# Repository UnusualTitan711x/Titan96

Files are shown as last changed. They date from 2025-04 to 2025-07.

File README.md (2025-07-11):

# Titan96  

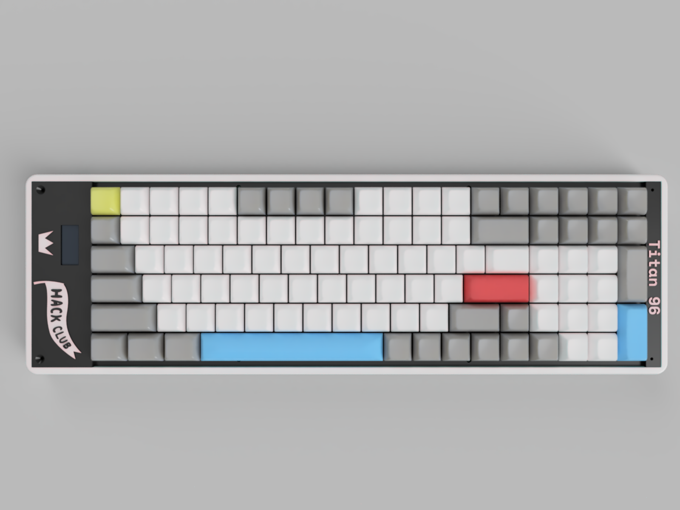
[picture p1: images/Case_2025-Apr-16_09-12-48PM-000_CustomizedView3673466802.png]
Titan96 render


**Titan96** is a compact 96% low-profile mechanical keyboard designed with sleek aesthetic. Powered by **KMK firmware** and built around the **Orpheus Pico microcontroller** by Hack Club.  

## Features  
- **96% Layout** – Compact yet functional, with all essential keys in a dense layout.  
- **Low-Profile Design** – Slimmer keys and case for a modern, ergonomic feel.  
- **KMK Firmware** – Highly customizable keymaps and macros using CircuitPython.  
- **Orpheus Pico MCU** – A powerful and open-source microcontroller by Hack Club.  
- **100 Keys** – Full numpad and navigation keys.  

## Parts
### CAD
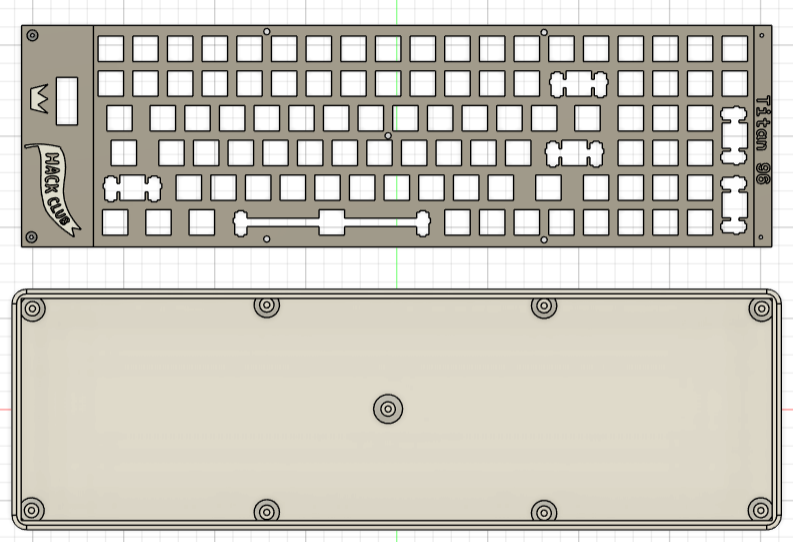
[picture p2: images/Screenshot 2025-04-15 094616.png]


### Schematic
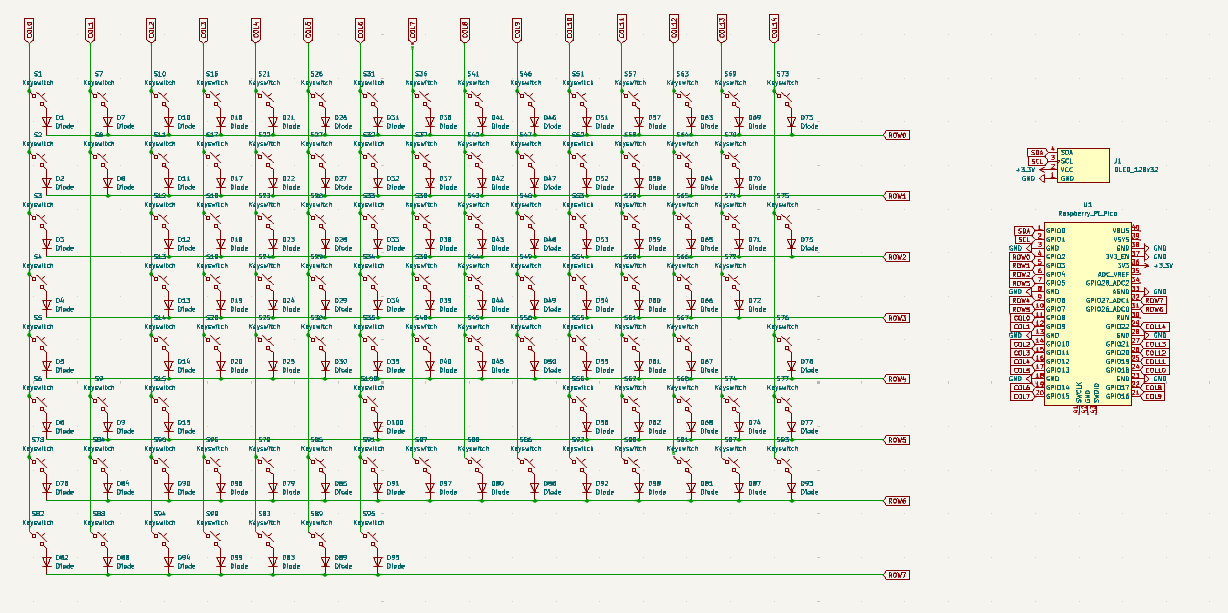
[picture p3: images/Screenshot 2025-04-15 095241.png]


### PCB
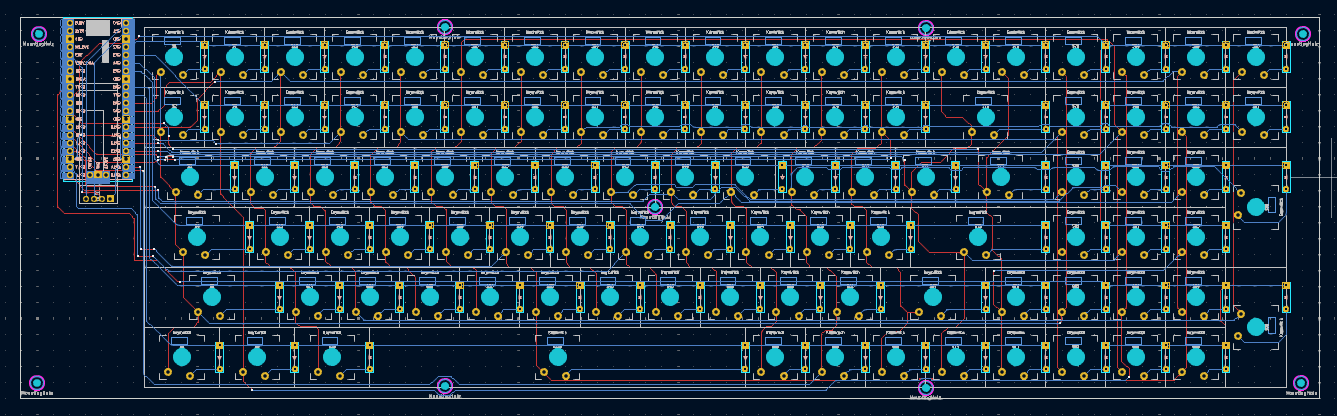
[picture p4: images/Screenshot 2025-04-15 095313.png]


## Firmware & Software  
The Titan96 runs on **KMK**, a Python-based keyboard firmware for CircuitPython-compatible microcontrollers.  

### Setup Instructions  
1. **Flash CircuitPython** onto the Orpheus Pico.  
2. **Install KMK firmware** by copying the KMK files to the microcontroller.  
3. **Configure keymap** by editing `code.py` to match your layout.  
4. **Customize macros, layers, and RGB** (if supported) via KMK.  

For detailed KMK setup, refer to the [official KMK documentation](https://github.com/KMKfw/kmk_firmware).  

## Bill of Materials (BOM)  
| Part | Quantity | Price | Link | Notes |  
|---|---|---|---|---|
| Orpheus Pico MCU | 1 | N/A | N/A | Microcontroller by Hack Club |  
| Low-profile mechanical switches | 100 | $40.07 | [AliExpress](https://www.aliexpress.com/item/1005004620638633.html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) | Gateron Low-Profile |  
| Keycaps | 100 | $22.14 | [AliExpress](https://www.aliexpress.com/item/1005007074678857.html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) | MX stems |  
| PCB | 1 | N/A |  N/A | Custom Titan96 PCB |  
| Plate | 1 |  N/A | N/A |3D printed |  
| Case | 1 | N/A | N/A | 3D printed |  
| Diodes | 100 | $4.7 | [AliExpress](https://www.aliexpress.com/item/1005004333197874.html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) | 1N4148 |  
| Stabilizers | 2u x 5, 6.5u x 1 | $15.58 | [AliExpress](https://www.aliexpress.com/item/1005005296240590.html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) | For larger keys (spacebar, Enter, etc.) |  
| OLED Screen 128 x 32 | 1 | $5.36 | [AliExpress](https://www.aliexpress.com/item/1005008670382155.html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) | Screen |  
| M2 screws | 5 | $4.8 | [AliExpress](https://www.aliexpress.com/item/1005004533251852.html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) | To screw the plate into the case |
| M2 threaded inserts | 5 | $5.87 | [AliExpress](https://www.aliexpress.com/item/1005003582355741.html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) | To screw the plate into the case |
 
*NB: All these prices include shipping to Cameroon*

Total : $98.52
## License  
This project is open-source under the **MIT License**.  

## Extra Renders
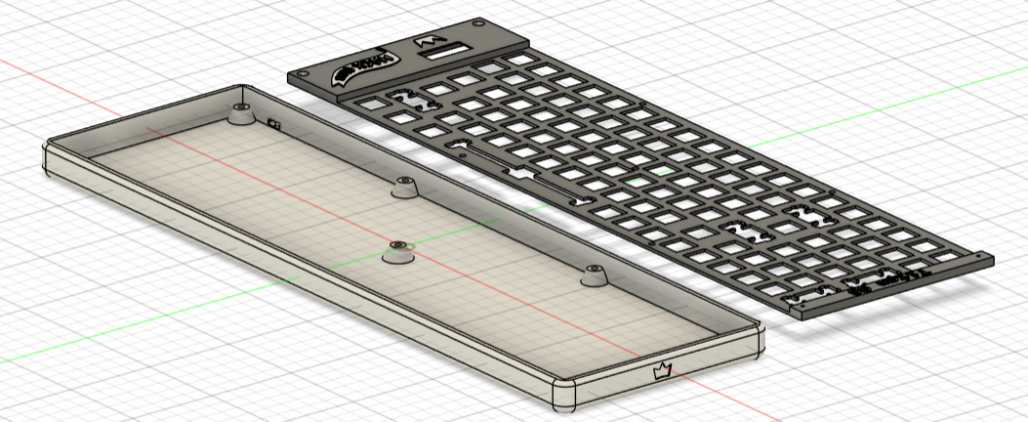
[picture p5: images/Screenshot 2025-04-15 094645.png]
3D Model above

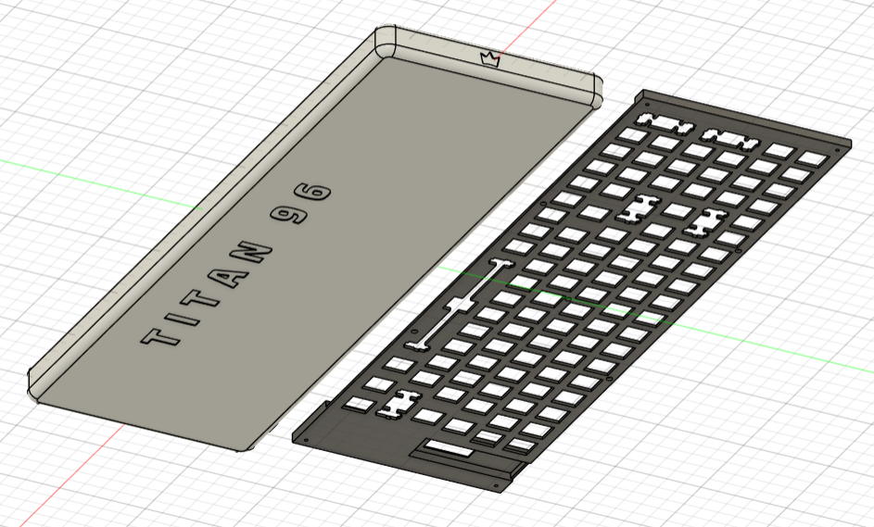
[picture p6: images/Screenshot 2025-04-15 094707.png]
3D Model below

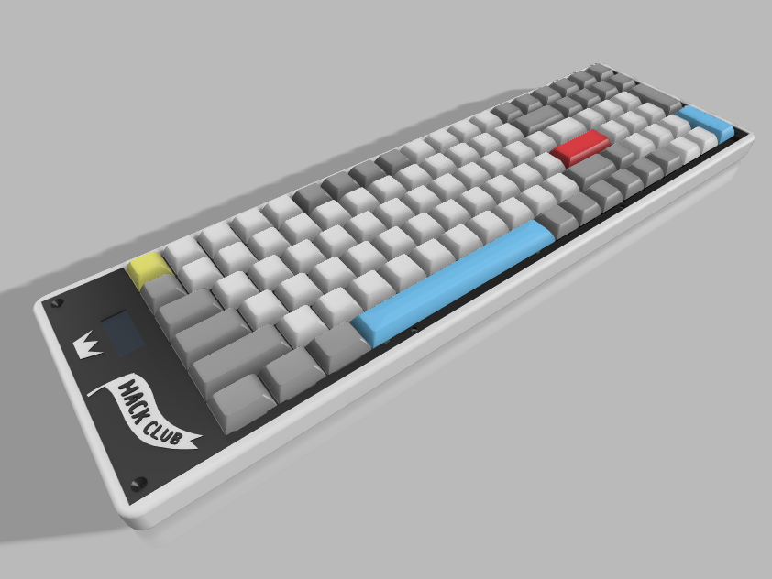
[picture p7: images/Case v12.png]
Full render

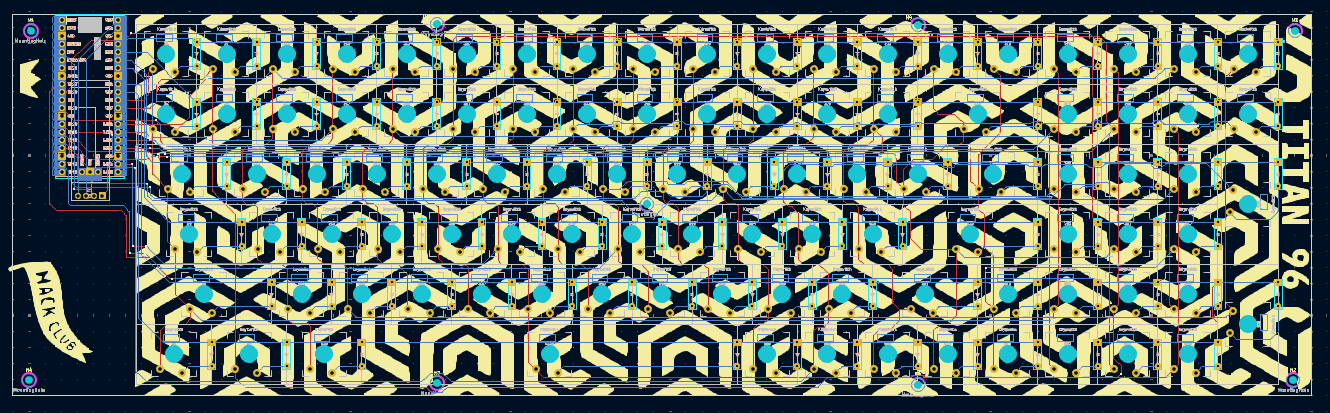
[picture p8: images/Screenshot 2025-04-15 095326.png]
PCB with Silkscreen Art


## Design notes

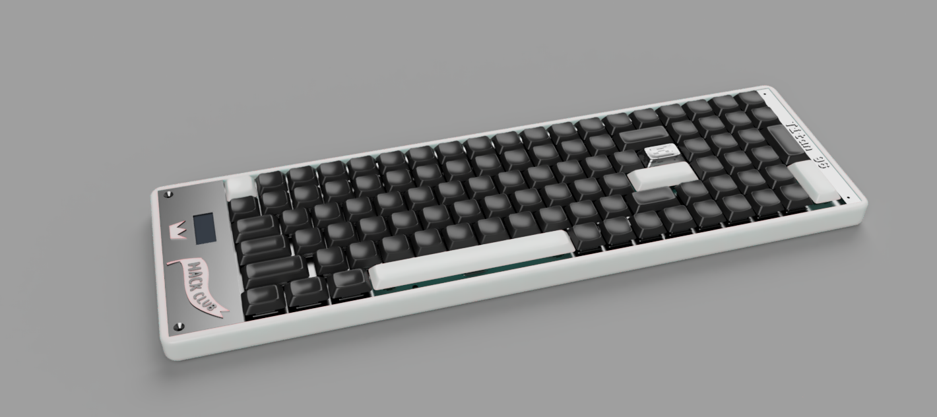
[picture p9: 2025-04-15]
images/26091cd3-cad4-45ae-b3a8-d274d9b3df26.PNG

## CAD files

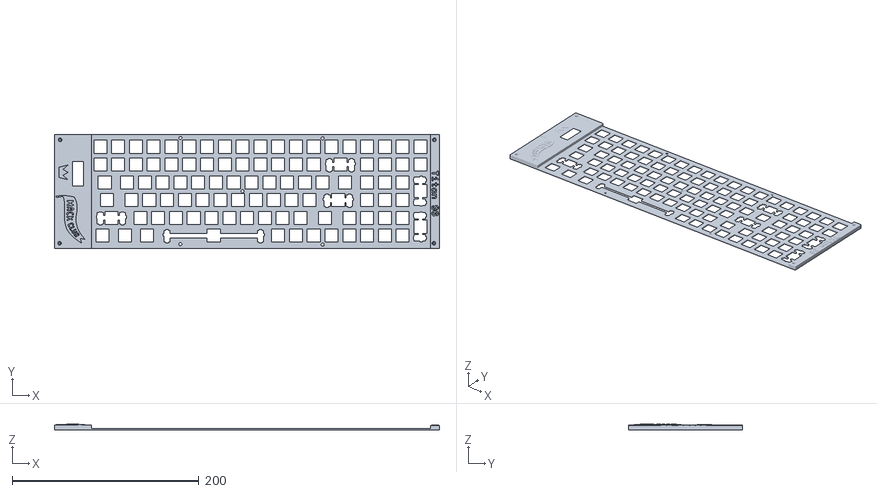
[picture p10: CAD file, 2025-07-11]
production/Plate.stl
412.4 x 121.6 x 6.50

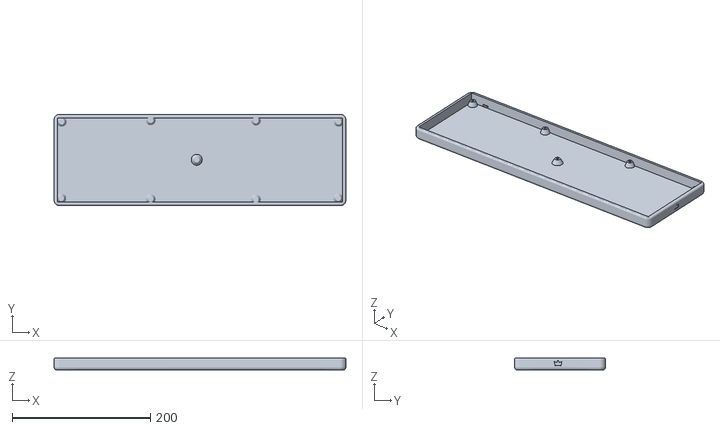
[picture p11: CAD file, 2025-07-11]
production/Case.stl
422.8 x 132.0 x 18.0

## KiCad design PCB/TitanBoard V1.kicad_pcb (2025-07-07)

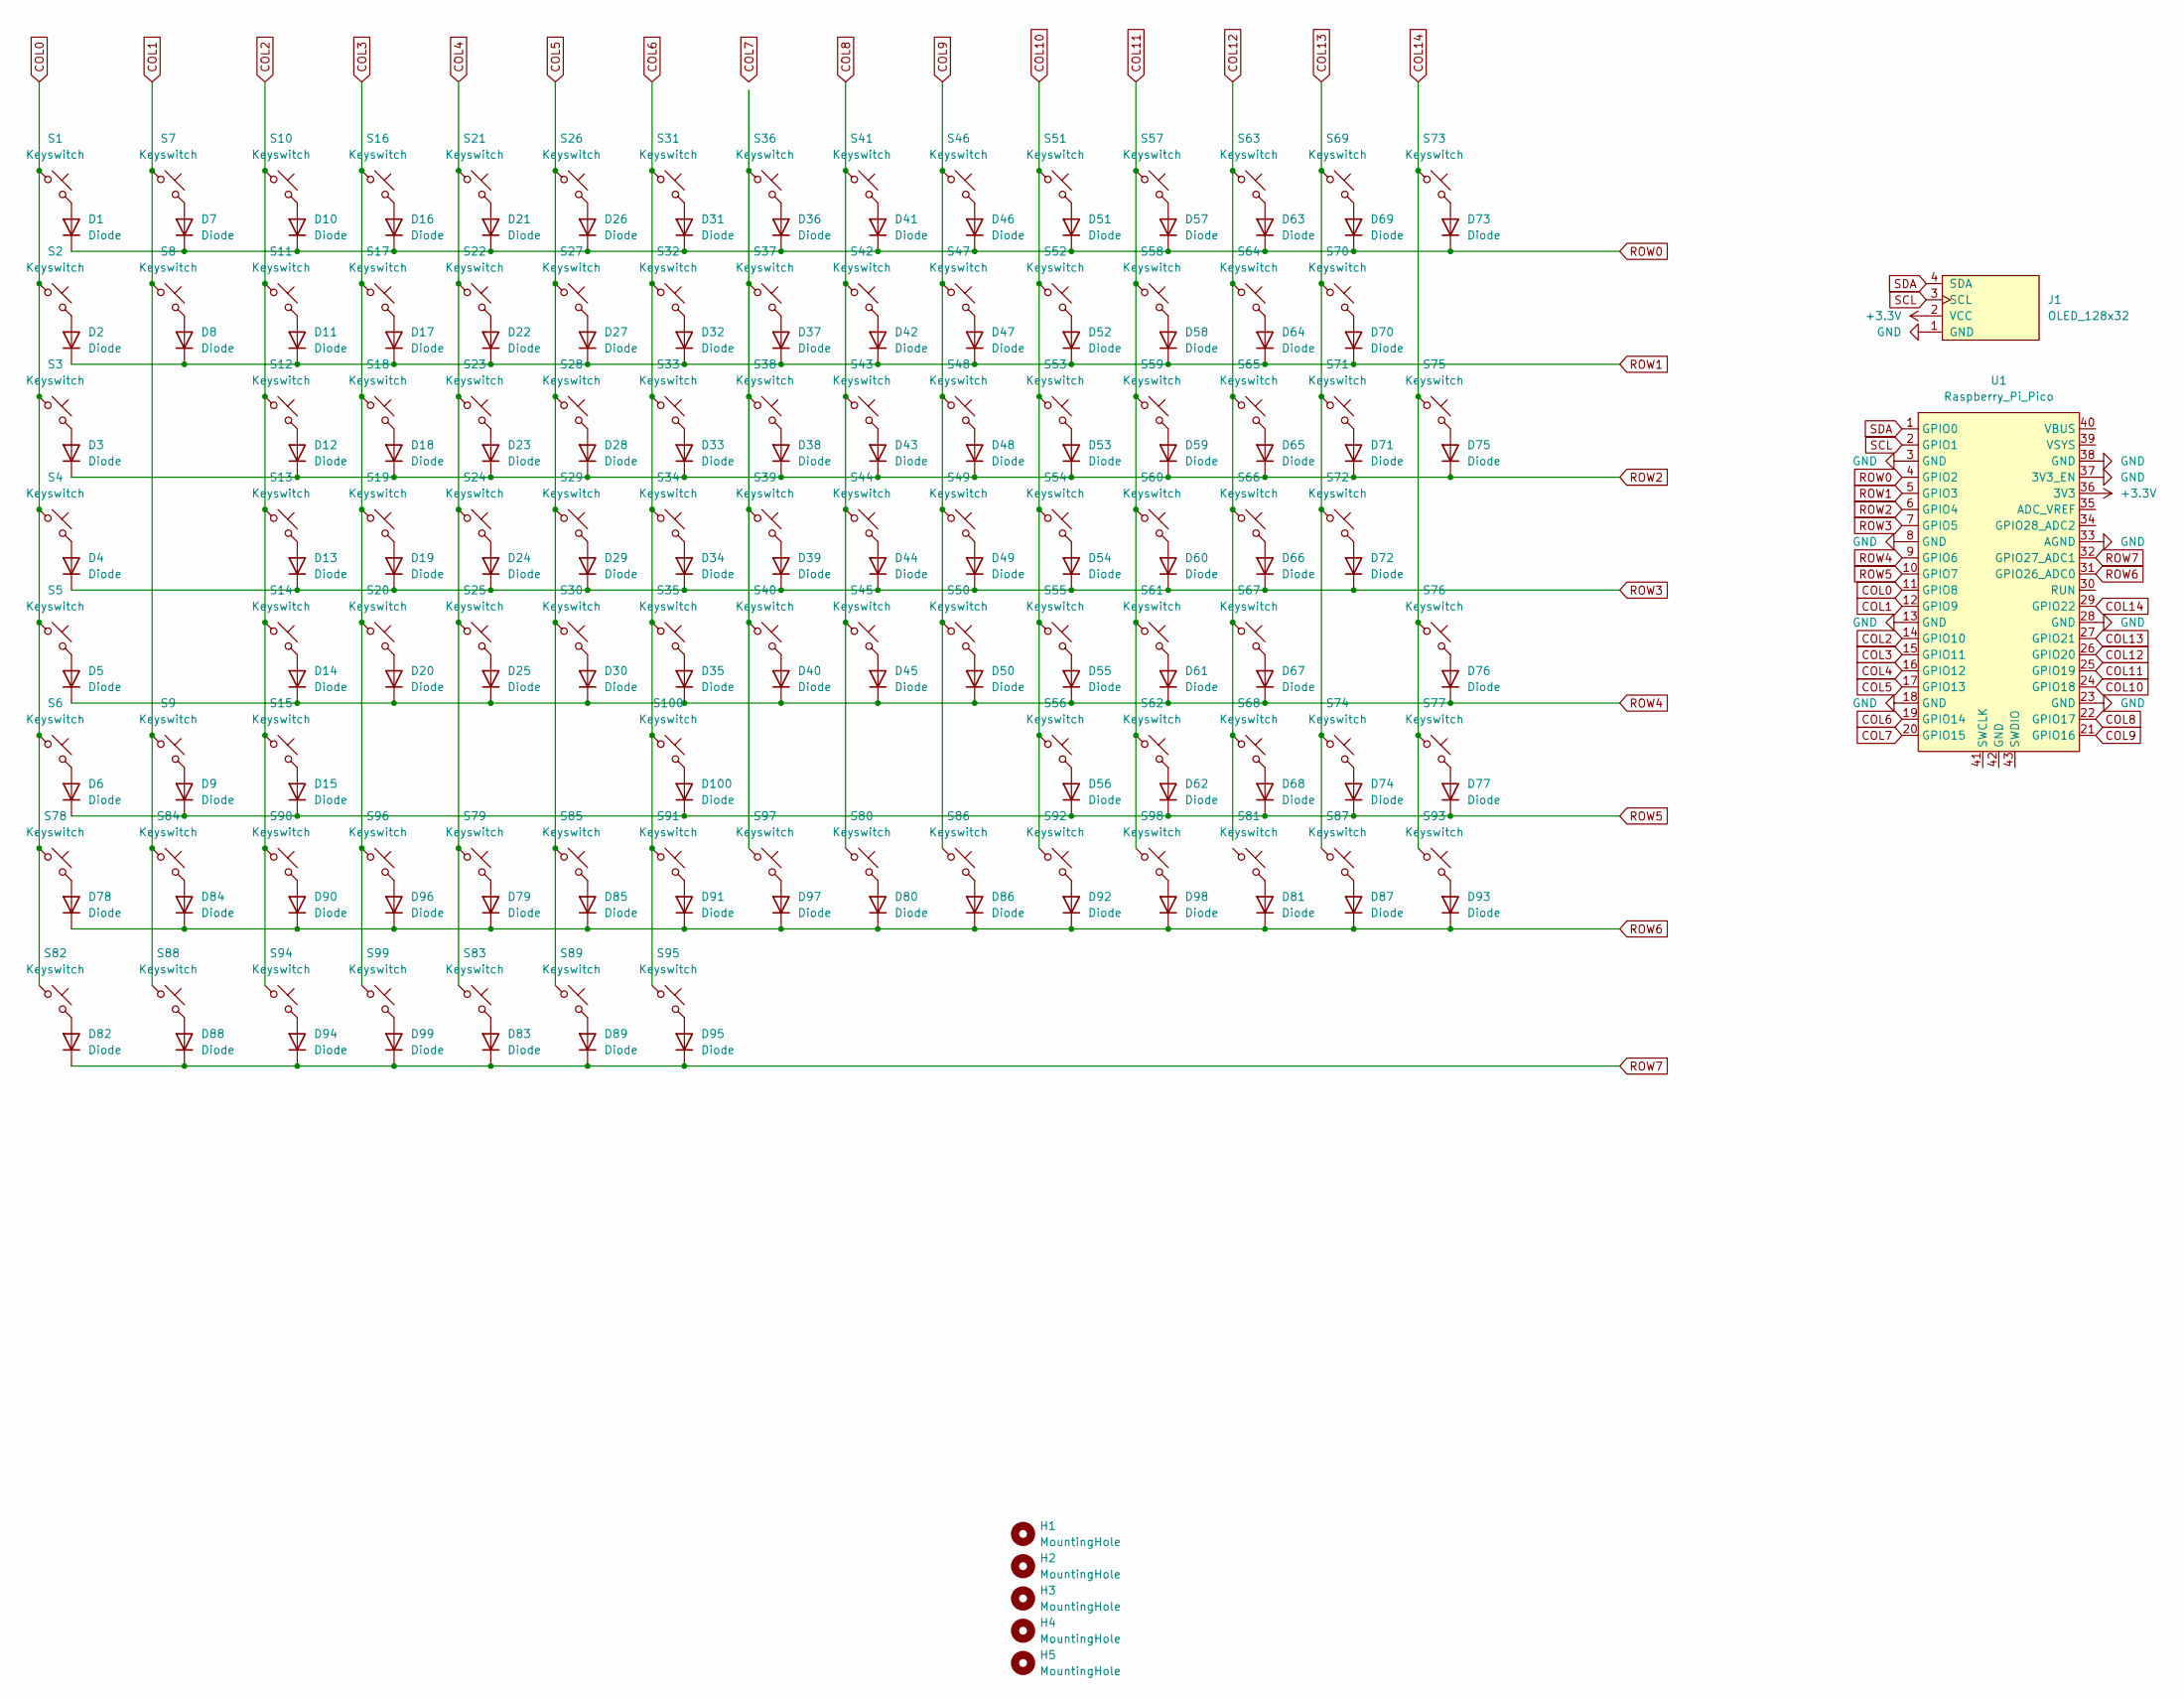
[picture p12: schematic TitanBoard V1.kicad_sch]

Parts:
D1, D2, D3, D4, D5, D6, D7, D8, D9, D10, D11, D12, D13, D14, D15, D16, D17, D18, D19, D20, D21, D22, D23, D24, D25, D26, D27, D28, D29, D30, D31, D32, D33, D34, D35, D36, D37, D38, D39, D40, D41, D42, D43, D44, D45, D46, D47, D48, D49, D50, D51, D52, D53, D54, D55, D56, D57, D58, D59, D60, D61, D62, D63, D64, D65, D66, D67, D68, D69, D70, D71, D72, D73, D74, D75, D76, D77, D78, D79, D80, D81, D82, D83, D84, D85, D86, D87, D88, D89, D90, D91, D92, D93, D94, D95, D96, D97, D98, D99, D100: Diode; Diode_DO-35
H1, H2, H3, H4, H5: MountingHole; MountingHole_2.2mm_M2
J1: OLED_128x32
S1, S2, S7, S8, S10, S11, S12, S13, S14, S16, S17, S18, S19, S20, S21, S22, S23, S24, S25, S26, S27, S28, S29, S30, S31, S32, S33, S34, S35, S36, S37, S38, S39, S40, S41, S42, S43, S44, S45, S46, S47, S48, S49, S50, S51, S52, S53, S54, S55, S56, S57, S58, S59, S60, S61, S62, S63, S64, S65, S66, S68, S69, S71, S73, S74, S76, S77, S78, S79, S80, S81, S82, S83, S84, S85, S86, S87, S88, S89, S90, S91, S92, S93, S94, S95, S96, S97: Keyswitch; Gateron-KS33-Solderable-1U
S3, S75: Keyswitch; Gateron-KS33-Solderable-1.5U
S4, S67: Keyswitch; Gateron-KS33-Solderable-1.75U
S5, S72: Keyswitch; Gateron-KS33-Solderable-2.25U
S6, S9, S15: Keyswitch; Gateron-KS33-Solderable-1.25U
S70, S98, S99: Keyswitch; Gateron-KS33-Solderable-2U
S100: Keyswitch; Gateron-KS33-Solderable-6.25U
U1: Raspberry_Pi_Pico

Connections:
+3.3V: J1.2 (VCC), U1.36 (3V3)
COL0: S1.1, S2.1, S3.1, S4.1, S5.1, S6.1, S78.1, S82.1, U1.11 (GPIO8)
COL1: S7.1, S8.1, S9.1, S84.1, S88.1, U1.12 (GPIO9)
COL2: S10.1, S11.1, S12.1, S13.1, S14.1, S15.1, S90.1, S94.1, U1.14 (GPIO10)
COL3: S16.1, S17.1, S18.1, S19.1, S20.1, S96.1, S99.1, U1.15 (GPIO11)
COL4: S21.1, S22.1, S23.1, S24.1, S25.1, S79.1, S83.1, U1.16 (GPIO12)
COL5: S26.1, S27.1, S28.1, S29.1, S30.1, S85.1, S89.1, U1.17 (GPIO13)
COL6: S31.1, S32.1, S33.1, S34.1, S35.1, S91.1, S95.1, S100.1, U1.19 (GPIO14)
COL7: U1.20 (GPIO15)
COL8: S41.1, S42.1, S43.1, S44.1, S45.1, S80.1, U1.22 (GPIO17)
COL9: S46.1, S47.1, S48.1, S49.1, S50.1, S86.1, U1.21 (GPIO16)
COL10: S51.1, S52.1, S53.1, S54.1, S55.1, S56.1, S92.1, U1.24 (GPIO18)
COL11: S57.1, S58.1, S59.1, S60.1, S61.1, S62.1, S98.1, U1.25 (GPIO19)
COL12: S63.1, S64.1, S65.1, S66.1, S67.1, S68.1, U1.26 (GPIO20)
COL13: S69.1, S70.1, S71.1, S72.1, S74.1, S87.1, U1.27 (GPIO21)
COL14: S73.1, S75.1, S76.1, S77.1, S93.1, U1.29 (GPIO22)
GND: J1.1 (GND), U1.3 (GND), U1.8 (GND), U1.13 (GND), U1.18 (GND), U1.23 (GND), U1.28 (GND), U1.33 (AGND), U1.37 (3V3_EN), U1.38 (GND)
unnamed: D1.2 (A), S1.2
unnamed: D2.2 (A), S2.2
unnamed: D3.2 (A), S3.2
unnamed: D4.2 (A), S4.2
unnamed: D5.2 (A), S5.2
unnamed: D6.2 (A), S6.2
unnamed: D7.2 (A), S7.2
unnamed: D8.2 (A), S8.2
unnamed: D9.2 (A), S9.2
unnamed: D10.2 (A), S10.2
unnamed: D11.2 (A), S11.2
unnamed: D12.2 (A), S12.2
unnamed: D13.2 (A), S13.2
unnamed: D14.2 (A), S14.2
unnamed: D15.2 (A), S15.2
unnamed: D16.2 (A), S16.2
unnamed: D17.2 (A), S17.2
unnamed: D18.2 (A), S18.2
unnamed: D19.2 (A), S19.2
unnamed: D20.2 (A), S20.2
unnamed: D21.2 (A), S21.2
unnamed: D22.2 (A), S22.2
unnamed: D23.2 (A), S23.2
unnamed: D24.2 (A), S24.2
unnamed: D25.2 (A), S25.2
unnamed: D26.2 (A), S26.2
unnamed: D27.2 (A), S27.2
unnamed: D28.2 (A), S28.2
unnamed: D29.2 (A), S29.2
unnamed: D30.2 (A), S30.2
unnamed: D31.2 (A), S31.2
unnamed: D32.2 (A), S32.2
unnamed: D33.2 (A), S33.2
unnamed: D34.2 (A), S34.2
unnamed: D35.2 (A), S35.2
unnamed: D36.2 (A), S36.2
unnamed: D37.2 (A), S37.2
unnamed: D38.2 (A), S38.2
unnamed: D39.2 (A), S39.2
unnamed: D40.2 (A), S40.2
unnamed: D41.2 (A), S41.2
unnamed: D42.2 (A), S42.2
unnamed: D43.2 (A), S43.2
unnamed: D44.2 (A), S44.2
unnamed: D45.2 (A), S45.2
unnamed: D46.2 (A), S46.2
unnamed: D47.2 (A), S47.2
unnamed: D48.2 (A), S48.2
unnamed: D49.2 (A), S49.2
unnamed: D50.2 (A), S50.2
unnamed: D51.2 (A), S51.2
unnamed: D52.2 (A), S52.2
unnamed: D53.2 (A), S53.2
unnamed: D54.2 (A), S54.2
unnamed: D55.2 (A), S55.2
unnamed: D56.2 (A), S56.2
unnamed: D57.2 (A), S57.2
unnamed: D58.2 (A), S58.2
unnamed: D59.2 (A), S59.2
unnamed: D60.2 (A), S60.2
unnamed: D61.2 (A), S61.2
unnamed: D62.2 (A), S62.2
unnamed: D63.2 (A), S63.2
unnamed: D64.2 (A), S64.2
unnamed: D65.2 (A), S65.2
unnamed: D66.2 (A), S66.2
unnamed: D67.2 (A), S67.2
unnamed: D68.2 (A), S68.2
unnamed: D69.2 (A), S69.2
unnamed: D70.2 (A), S70.2
unnamed: D71.2 (A), S71.2
unnamed: D72.2 (A), S72.2
unnamed: D73.2 (A), S73.2
unnamed: D74.2 (A), S74.2
unnamed: D75.2 (A), S75.2
unnamed: D76.2 (A), S76.2
unnamed: D77.2 (A), S77.2
unnamed: D78.2 (A), S78.2
unnamed: D79.2 (A), S79.2
unnamed: D80.2 (A), S80.2
unnamed: D81.2 (A), S81.2
unnamed: D82.2 (A), S82.2
unnamed: D83.2 (A), S83.2
unnamed: D84.2 (A), S84.2
unnamed: D85.2 (A), S85.2
unnamed: D86.2 (A), S86.2
unnamed: D87.2 (A), S87.2
unnamed: D88.2 (A), S88.2
unnamed: D89.2 (A), S89.2
unnamed: D90.2 (A), S90.2
unnamed: D91.2 (A), S91.2
unnamed: D92.2 (A), S92.2
unnamed: D93.2 (A), S93.2
unnamed: D94.2 (A), S94.2
unnamed: D95.2 (A), S95.2
unnamed: D96.2 (A), S96.2
unnamed: D97.2 (A), S97.2
unnamed: D98.2 (A), S98.2
unnamed: D99.2 (A), S99.2
unnamed: D100.2 (A), S100.2
unnamed: S36.1, S37.1, S38.1, S39.1, S40.1, S97.1
ROW0: D1.1 (K), D7.1 (K), D10.1 (K), D16.1 (K), D21.1 (K), D26.1 (K), D31.1 (K), D36.1 (K), D41.1 (K), D46.1 (K), D51.1 (K), D57.1 (K), D63.1 (K), D69.1 (K), D73.1 (K), U1.4 (GPIO2)
ROW1: D2.1 (K), D8.1 (K), D11.1 (K), D17.1 (K), D22.1 (K), D27.1 (K), D32.1 (K), D37.1 (K), D42.1 (K), D47.1 (K), D52.1 (K), D58.1 (K), D64.1 (K), D70.1 (K), U1.5 (GPIO3)
ROW2: D3.1 (K), D12.1 (K), D18.1 (K), D23.1 (K), D28.1 (K), D33.1 (K), D38.1 (K), D43.1 (K), D48.1 (K), D53.1 (K), D59.1 (K), D65.1 (K), D71.1 (K), D75.1 (K), U1.6 (GPIO4)
ROW3: D4.1 (K), D13.1 (K), D19.1 (K), D24.1 (K), D29.1 (K), D34.1 (K), D39.1 (K), D44.1 (K), D49.1 (K), D54.1 (K), D60.1 (K), D66.1 (K), D72.1 (K), U1.7 (GPIO5)
ROW4: D5.1 (K), D14.1 (K), D20.1 (K), D25.1 (K), D30.1 (K), D35.1 (K), D40.1 (K), D45.1 (K), D50.1 (K), D55.1 (K), D61.1 (K), D67.1 (K), D76.1 (K), U1.9 (GPIO6)
ROW5: D6.1 (K), D9.1 (K), D15.1 (K), D56.1 (K), D62.1 (K), D68.1 (K), D74.1 (K), D77.1 (K), D100.1 (K), U1.10 (GPIO7)
ROW6: D78.1 (K), D79.1 (K), D80.1 (K), D81.1 (K), D84.1 (K), D85.1 (K), D86.1 (K), D87.1 (K), D90.1 (K), D91.1 (K), D92.1 (K), D93.1 (K), D96.1 (K), D97.1 (K), D98.1 (K), U1.31 (GPIO26_ADC0)
ROW7: D82.1 (K), D83.1 (K), D88.1 (K), D89.1 (K), D94.1 (K), D95.1 (K), D99.1 (K), U1.32 (GPIO27_ADC1)
SCL: J1.3 (SCL), U1.2 (GPIO1)
SDA: J1.4 (SDA), U1.1 (GPIO0)

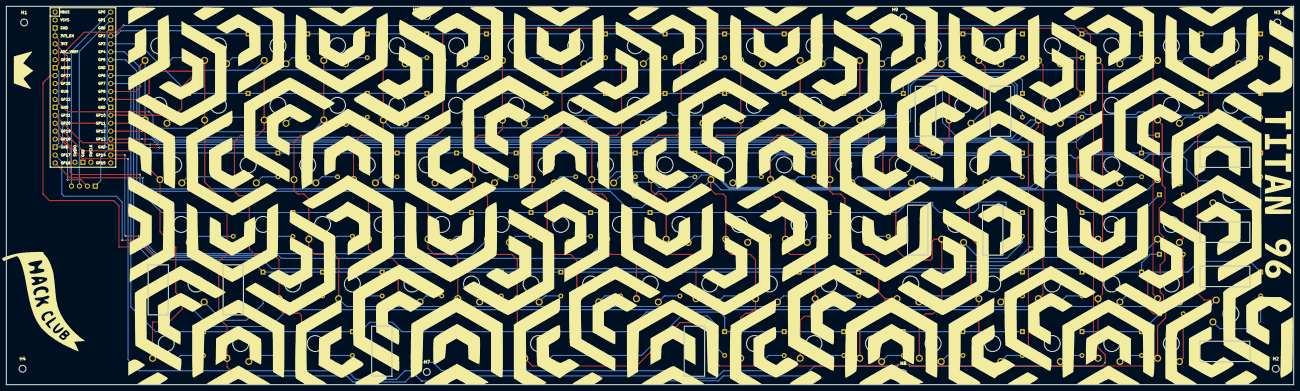
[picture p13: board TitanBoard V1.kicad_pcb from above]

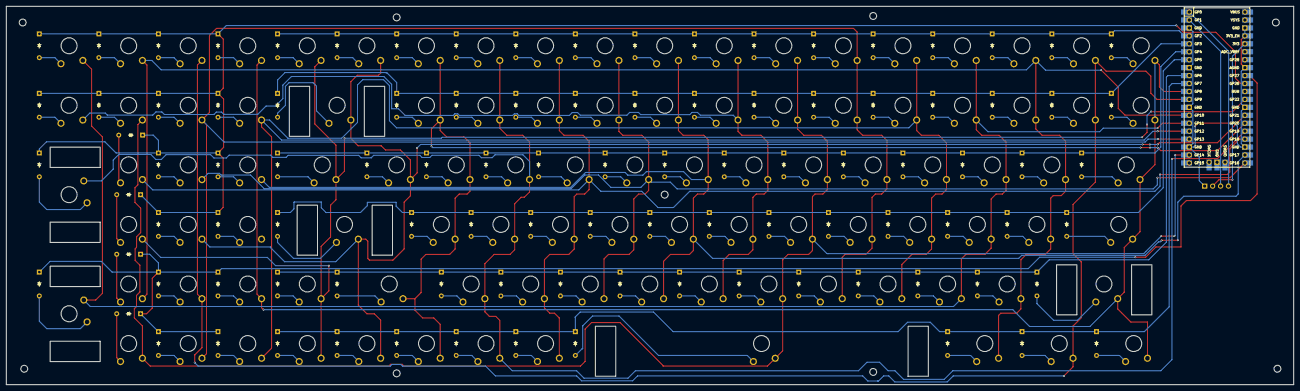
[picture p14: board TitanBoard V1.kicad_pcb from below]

Board: 2 copper layers, 411.8 x 121.0 mm, 211 parts (101 on the bottom side), 127 nets.

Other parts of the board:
H6, H7, H8, H9: MountingHole; MountingHole_2.2mm_M2

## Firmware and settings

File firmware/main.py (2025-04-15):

# You import all the IOs of your board
import board

# These are imports from the kmk library
from kmk.kmk_keyboard import KMKKeyboard
from kmk.scanners import KeysScanner, DiodeOrientation
from kmk.keys import KC
from kmk.modules.macros import Press, Release, Tap, Macros

# This is the main instance of your keyboard
keyboard = KMKKeyboard()

# Tell kmk we are not using a key matrix
keyboard.matrix = KeysScanner(
    row_pins=(board.GP2, board.GP3, board.GP4, board.GP5, board.GP6, board.GP7, board.GP26, board.GP27),
    col_pins=(board.GP8, board.GP9, board.GP10, board.GP11, board.GP12, board.GP13, board.GP14, board.GP15, board.GP16, board.GP17, board.GP18, board.GP19, board.GP20, board.GP21, board.GP22),
    diode_orientation=DiodeOrientation.COL2ROW,
)

# Here you define the buttons corresponding to the pins
# Look here for keycodes: https://github.com/KMKfw/kmk_firmware/blob/main/docs/en/keycodes.md
# And here for macros: https://github.com/KMKfw/kmk_firmware/blob/main/docs/en/macros.md
keyboard.keymap = [
    [
        # Row 1: F-keys (optional if you wire them)
        [KC.ESC, KC.F1, KC.F2, KC.F3, KC.F4, KC.F5, KC.F6, KC.F7, KC.F8, KC.F9, KC.F10, KC.F11, KC.F12, KC.PSCR, KC.SLCK]

        # Row 2
        [KC.GRV, KC._1, KC._2, KC._3, KC._4, KC._5, KC._6, KC._7, KC._8, KC._9, KC._0, KC.MINS, KC.EQUAL, KC.BSPC, KC.NO]

        # Row 3
        [KC.TAB, KC.NO, KC.Q, KC.W, KC.E, KC.R, KC.T, KC.Y, KC.U, KC.I, KC.O, KC.P, KC.LBRC, KC.RBRC, KC.BSLS]

        # Row 4
        [KC.CAPS, KC.NO, KC.A, KC.S, KC.D, KC.F, KC.G, KC.H, KC.J, KC.K, KC.L, KC.SCLN, KC.QUOT, KC.ENT, KC.NO]

        # Row 5
        [KC.LSFT, KC.NO, KC.Z, KC.X, KC.C, KC.V, KC.B, KC.N, KC.M, KC.COMM, KC.DOT, KC.SLSH, KC.RSFT, KC.NO, KC.UP]

        # Row 6 (Bottom row)
        [KC.LCTL, KC.LGUI, KC.LALT, KC.NO, KC.NO, KC.NO, KC.SPC, KC.NO, KC.NO, KC.NO, KC.RALT, KC.RGUI, KC.RCTL, KC.LEFT, KC.DOWN]

        # Row 7 (Not Physical)
        [KC.INS, KC.CALC, KC.PGUP, KC.SCRL, KC.PSLS, KC.PAST, KC.PMNS, KC.P7, KC.P8, KC.P9, KC.PPLS, KC.P4, KC.P5, KC.P6]

        # Row 7 (Not Physical)
        [KC.LEFT, KC.P1, KC.P2, KC.P3, KC.PENT, KC.P0, KC.PDOT, KC.NO, KC.NO, KC.NO, KC.NO, KC.NO, KC.NO, KC.NO, KC.NO]
    ]
]

# Start kmk!
if __name__ == '__main__':
    keyboard.go()

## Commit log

2025-04-15 added PCB stuff
    [TitanBoard V1.kicad_pcb, TitanBoard V1.kicad_sch, matrix.kicad_sch]
2025-04-15 added case parts
    [Bottom.stl, Plate.stl]
2025-07-07 updated footprints
    made space for the plate mounted stabilizers
    [TitanBoard V1.kicad_pcb]
2025-07-11 updated CAD
    [Bottom.stl, Case.stl, Plate.stl]
